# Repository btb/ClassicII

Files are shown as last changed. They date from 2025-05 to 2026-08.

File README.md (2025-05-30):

# ClassicII

Reproduction of Macintosh Classic II

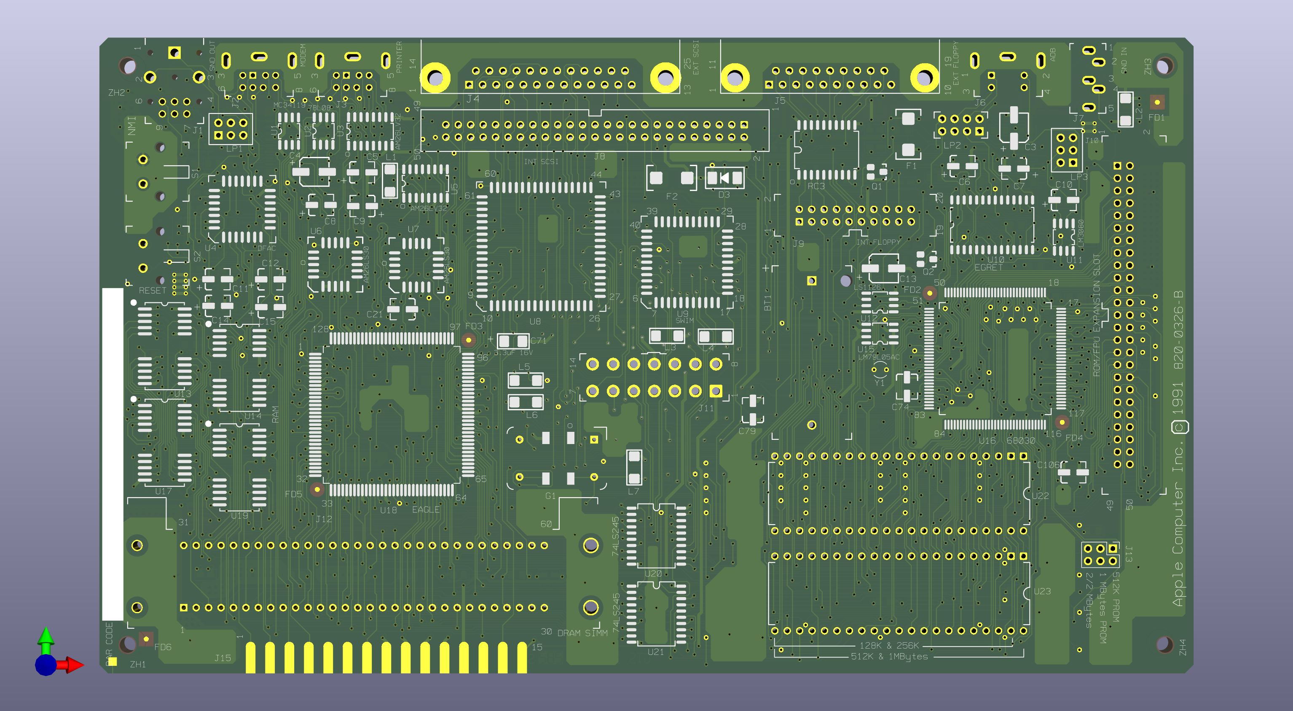
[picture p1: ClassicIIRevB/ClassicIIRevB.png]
Rendering of reproduced Class II logic board


This was reverse-engineered from a later-revision Classic II logic board. All components on the front side, and a handful of components on the back side, were removed, and the board was scanned.

Since my scanner isn't very accurate, scale-wise, the scans were resized and aligned to match the board's measurements.

The board was severely damaged by battery and capacitor leakage, but I was able to faithfully reproduce all connections.

The inner layers are used for various ground and power planes - you can make out a surprising amount of inner detail by backlighting the board and seeing what shines through the windows left by vias, etc., so these are also reproduced fairly accurately.

The [Bomarc schematics](documents/Bomarc%20schematics%20-%20corrected.pdf) for this board were useful as a reference, but they are for the earlier revision, and they do contain some inaccuracies.

## Issues

It's likely some of the signals of the undocumented Apple ASICs in [my schematic](ClassicIIRevB/ClassicIIRevB.pdf) aren't classified correctly.

The silkscreen markings of the PCB aren't as nice as I'd like yet.

There should be a "reloaded" version that will better serve those who need to replace their damaged boards. It should have footprints for both the older and the newer revision ROM chips. The footprints for the electrolytic caps should be widened to make them friendlier to replace with tantalums. The battery should accommodate a 2032 coin cell.

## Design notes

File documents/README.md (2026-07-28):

# Documents

## Classic_II_Schematic.pdf

Classic II schematics from Apple, posted to 68kmla forums after I did my reverse-engineering.

## Bomarc schematics - corrected.pdf

The Classic II schematics, as reverse-engineered by Bomarc Services, with corrections added by me.

## Developer Note.pdf

The Classic II Developer Note from Apple.

## Macintosh_Hardware_Overview_Feb91.pdf

Apple internal document describing the hardware of this era. The Classic II is referred to as "Apollo" here.

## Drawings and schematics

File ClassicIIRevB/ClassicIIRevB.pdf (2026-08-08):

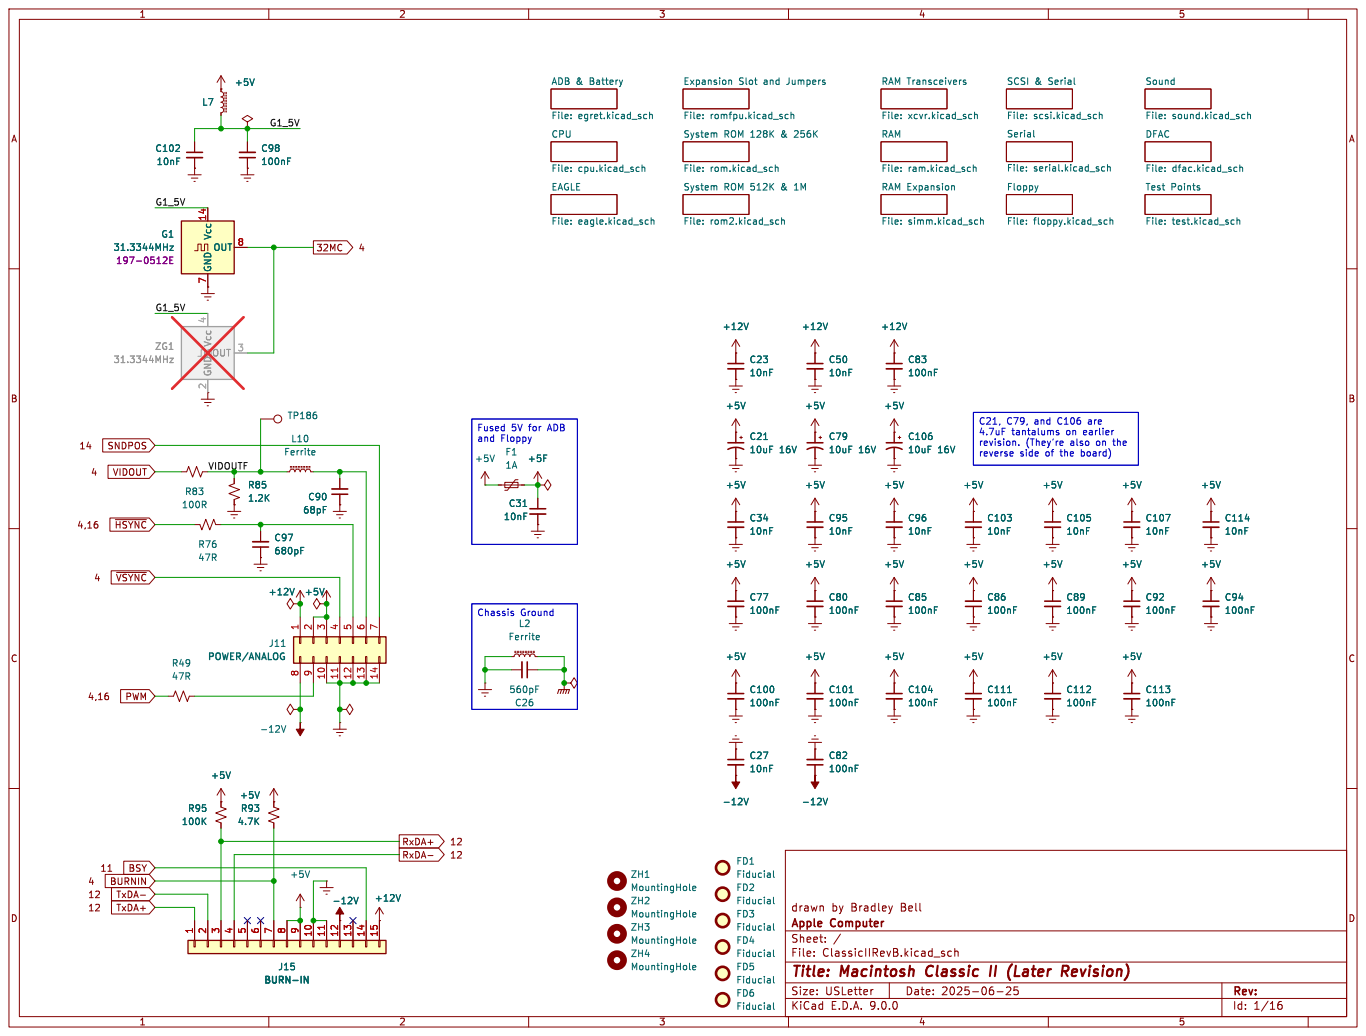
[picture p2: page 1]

Expansion Slot and Jumpers File: romfpu.kicad_sch EAGLE

File: dfac.kicad_sch Sound File: sound.kicad_sch Serial File: serial.kicad_sch RAM Transceivers File: xcvr.kicad_sch RAM

reverse side of the board) Fused 5V for ADB

L10 FerriteC90
and Floppy Chassis Ground C90

FD4 Fiducial FD2 Fiducial FD6 Fiducial FD1 Fiducial ZH3 MountingHole ZH2 MountingHole

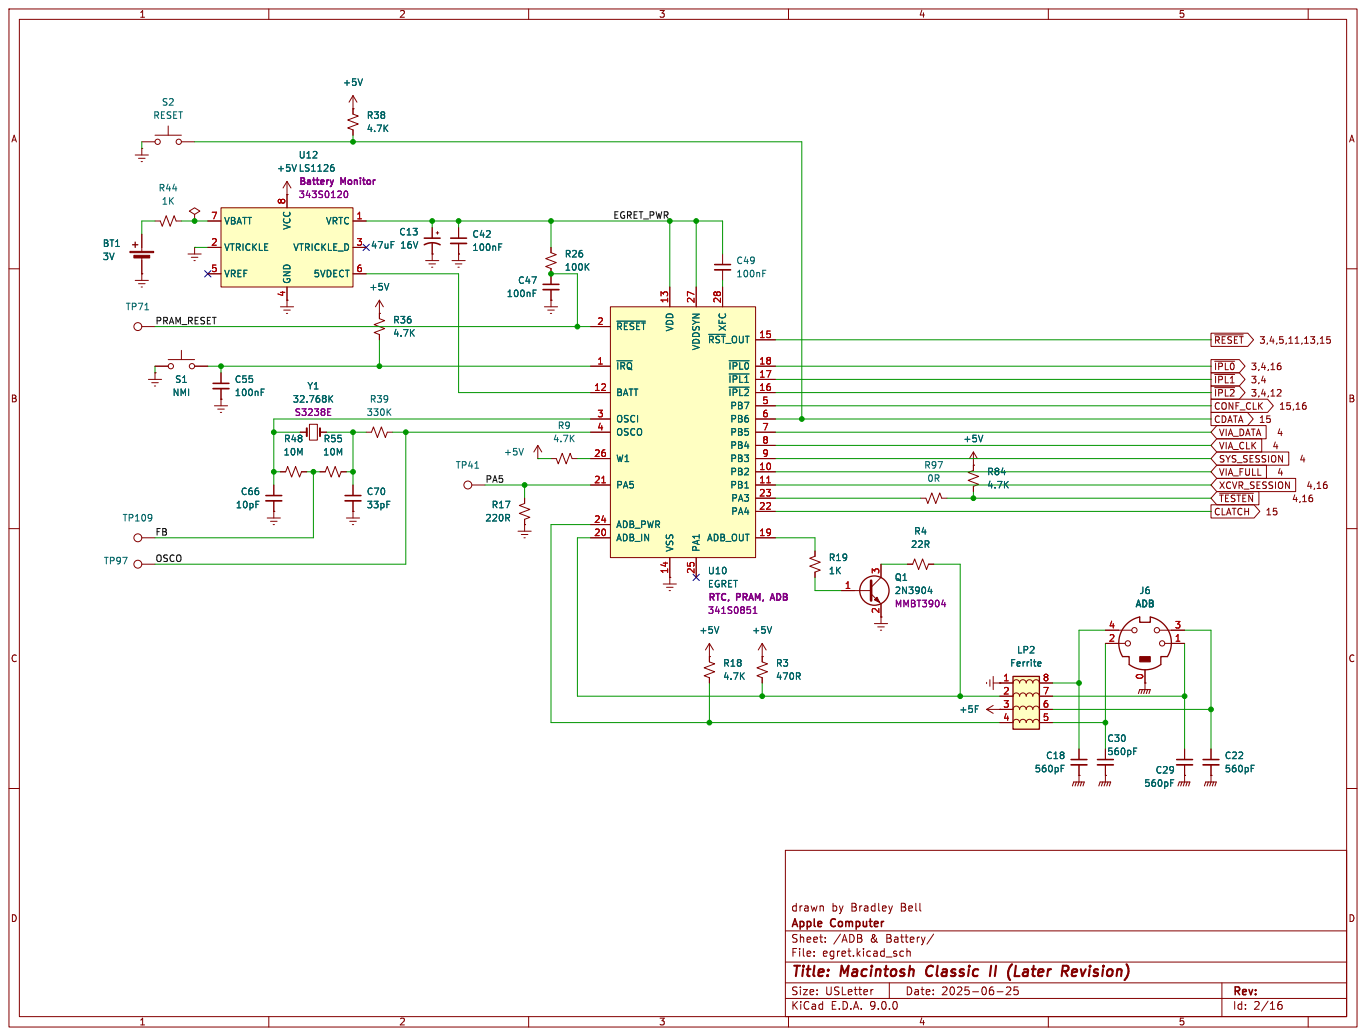
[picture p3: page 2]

4 VBATT 7 VTRICKLE 2 VREF 5 VRTC 1 VTRICKLE_D 3

U10 EGRET RTC, PRAM, ADB

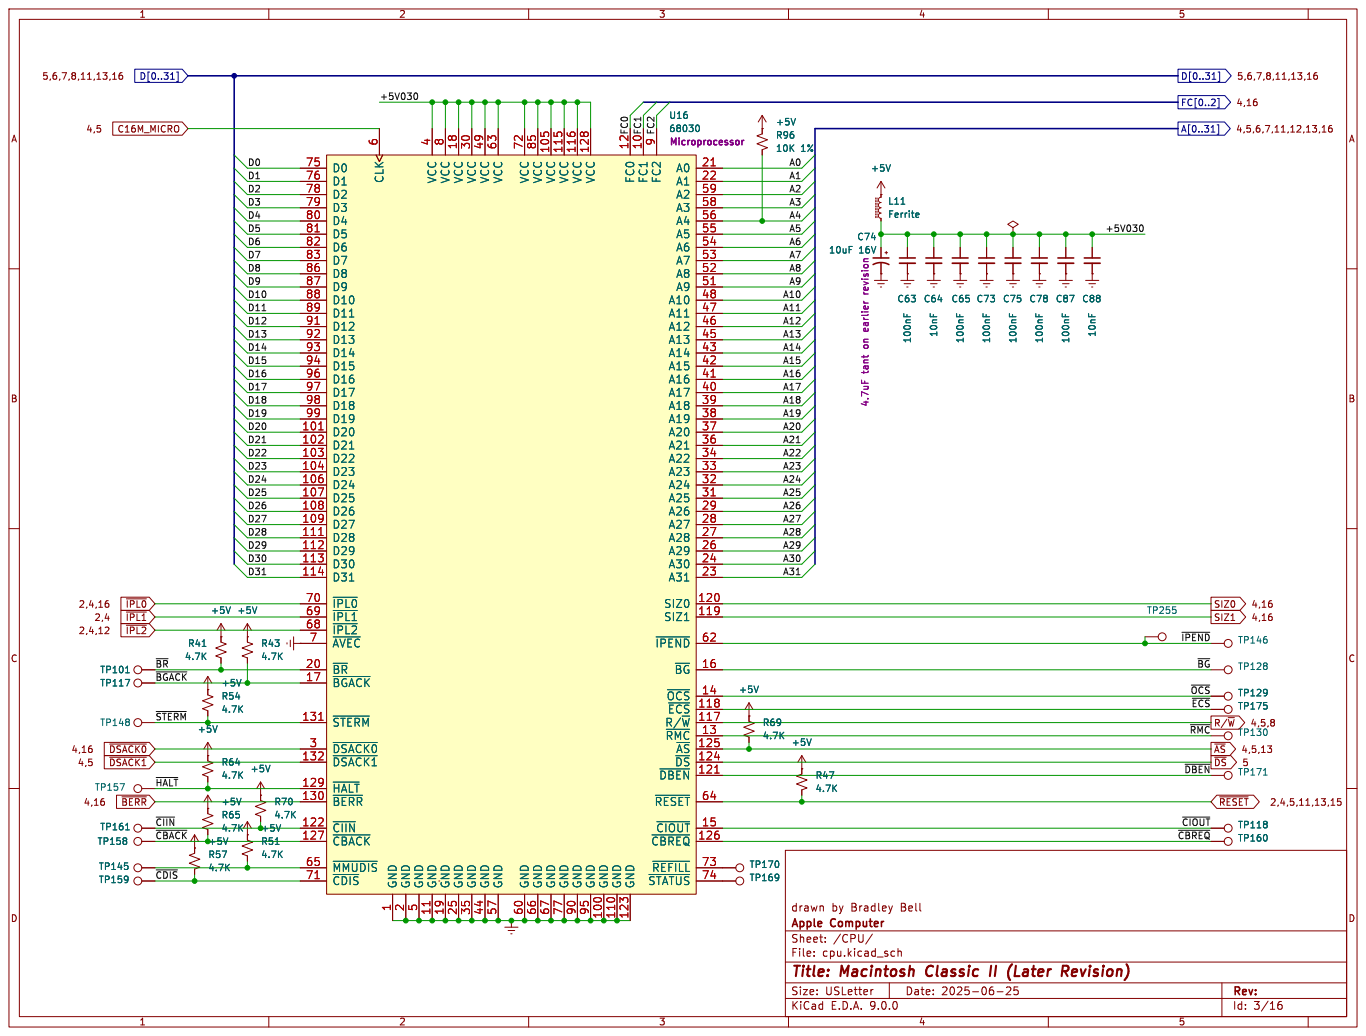
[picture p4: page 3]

8 GND 19 VCC 18 GND 25 VCC 30 GND 35 VCC 49 GND 44 VCC 63 GND 57 VCC 72 GND 60 VCC 85 GND 66 VCC 105 GND 67 VCC 115 GND 77 VCC 116 GND 90 VCC 128 GND 95 GND 100 GND 110 FC0 12 GND 123 FC1 10 FC2

9 A0 21 A1 22 A2 59 A3 58 A4 56 A5 55 A6 54 A7 53 A8 52 A9 51 A10 48 A11 47 A12 46 A13 45 A14 43 A15 42 A16 41 A17 40 A18 39 A19 38 A20 37 A21 36 A22 34 A23 33 A24 32 A25 31 A26 29 A27 28 A28 27 A29 26 A30 24 A31 23 SIZ0 120 SIZ1 119 ~{IPEND}62 ~{BG}16 ~{OCS}14 ~{ECS}118 R/~{W}117 ~{RMC}13 ~{AS}125 ~{DS}124 ~{DBEN}121 ~{RESET}64 ~{CIOUT}15 ~{CBREQ}126 ~{REFILL}73 ~{STATUS}74

10uF 16V4.7uF tant on earlier revision

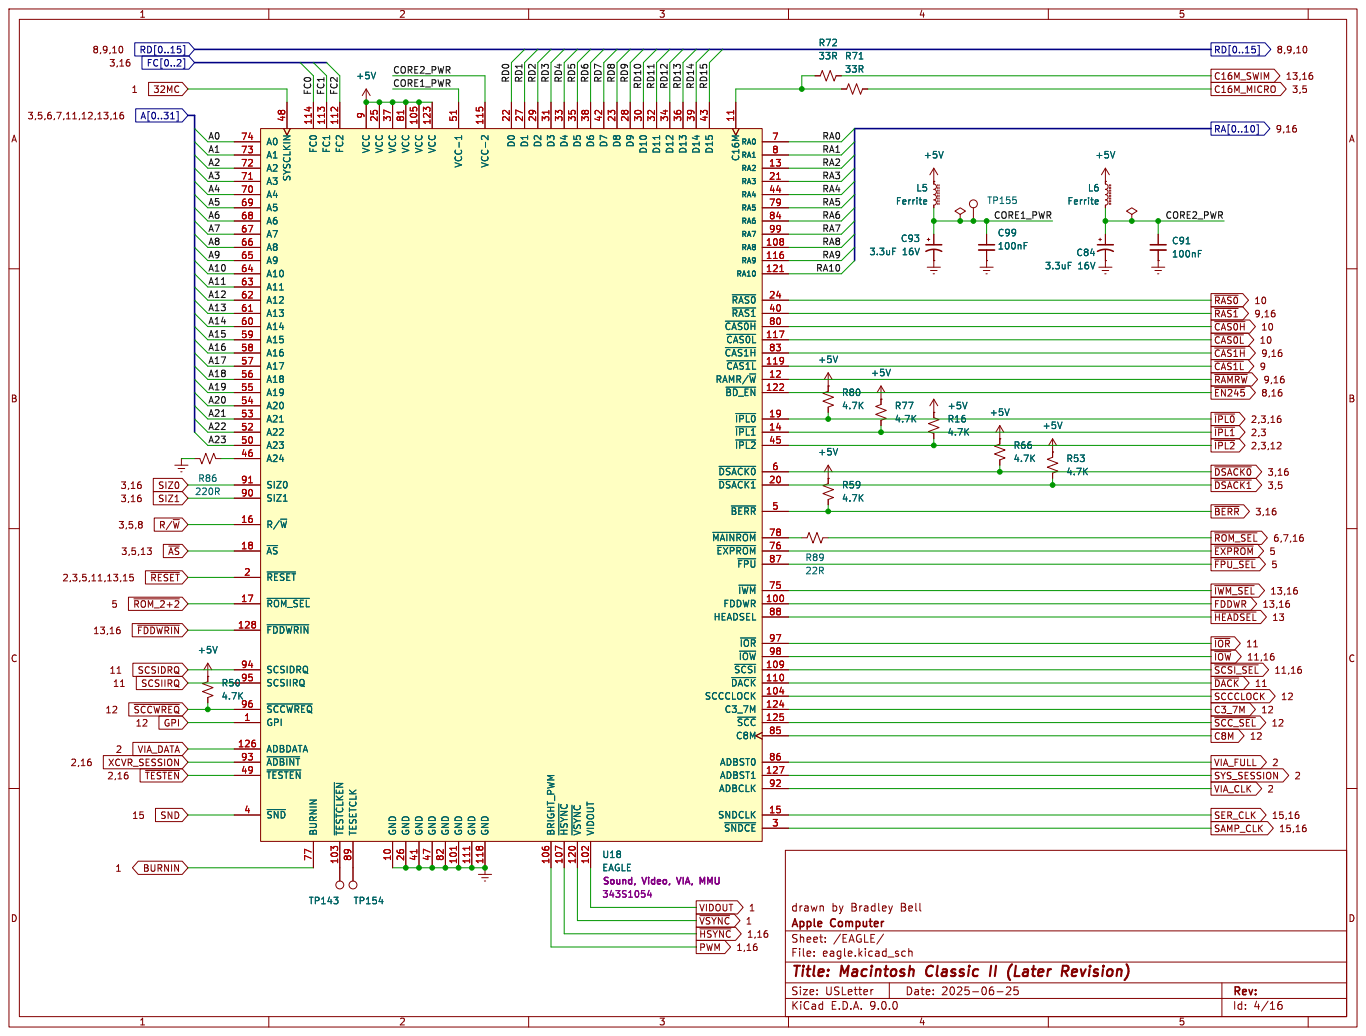
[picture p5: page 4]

9 VCC 25 VCC 37 GND 10 VCC 81 GND 26 VCC 105 GND 41 VCC 123 GND 47 GND 82 VCC-1 51 GND 101 GND 111 VCC-2 115 GND 118 D0 22 D1 27 D2 29 D3 31 BRIGHT_PWM 106 D4 33 ~{HSYNC} 107 D5 35 ~{VSYNC} 120 D6 38 VIDOUT 102 D7 42 D8 23 D9 28 D10 30 D11 32 D12 34 D13 36 D14 39 D15 43 C16M 11 RA0 7 RA1 8 RA2 13 RA3 21 RA4 44 RA5 79 RA6 84 RA7 99 RA8 108 RA9 116 RA10 121 ~{RAS0} 24 ~{RAS1} 40 ~{CAS0H} 80 ~{CAS0L}117 ~{CAS1H} 83 ~{CAS1L}119 RAMR/~{W} 12 ~{BD_EN}122 ~{IPL0} 19 ~{IPL1} 14 ~{IPL2} 45 ~{DSACK0} 6 ~{DSACK1} 20 ~{BERR} 5 ~{MAINROM}78 ~{EXPROM} 76 ~{FPU} 87 ~{IWM}75 FDDWR 100 HEADSEL 88 ~{IOR} 97 ~{IOW}98 ~{SCSI}109 ~{DACK}110 SCCCLOCK 104 C3_7M 124 ~{SCC}125 C8M 85 ADBST0 86 ADBST1 127 ADBCLK 92 SNDCLK 15 ~{SNDCE} 3 R50

9 VCC 25 VCC 37 GND 10 VCC 81 GND 26 VCC 105 GND 41 VCC 123 GND 47 GND 82 VCC-1 51 GND 101 GND 111 VCC-2 115 GND 118 D0 22 D1 27 D2 29 D3 31 BRIGHT_PWM 106 D4 33 ~{HSYNC} 107 D5 35 ~{VSYNC} 120 D6 38 VIDOUT 102 D7 42 D8 23 D9 28 D10 30 D11 32 D12 34 D13 36 D14 39 D15 43 C16M 11 RA0 7 RA1 8 RA2 13 RA3 21 RA4 44 RA5 79 RA6 84 RA7 99 RA8 108 RA9 116 RA10 121 ~{RAS0} 24 ~{RAS1} 40 ~{CAS0H} 80 ~{CAS0L}117 ~{CAS1H} 83 ~{CAS1L}119 RAMR/~{W} 12 ~{BD_EN}122 ~{IPL0} 19 ~{IPL1} 14 ~{IPL2} 45 ~{DSACK0} 6 ~{DSACK1} 20 ~{BERR} 5 ~{MAINROM}78 ~{EXPROM} 76 ~{FPU} 87 ~{IWM}75 FDDWR 100 HEADSEL 88 ~{IOR} 97 ~{IOW}98 ~{SCSI}109 ~{DACK}110 SCCCLOCK 104 C3_7M 124 ~{SCC}125 C8M 85 ADBST0 86 ADBST1 127 ADBCLK 92 SNDCLK 15 ~{SNDCE} 3 U18 EAGLE

Sound, Video, VIA, MMU

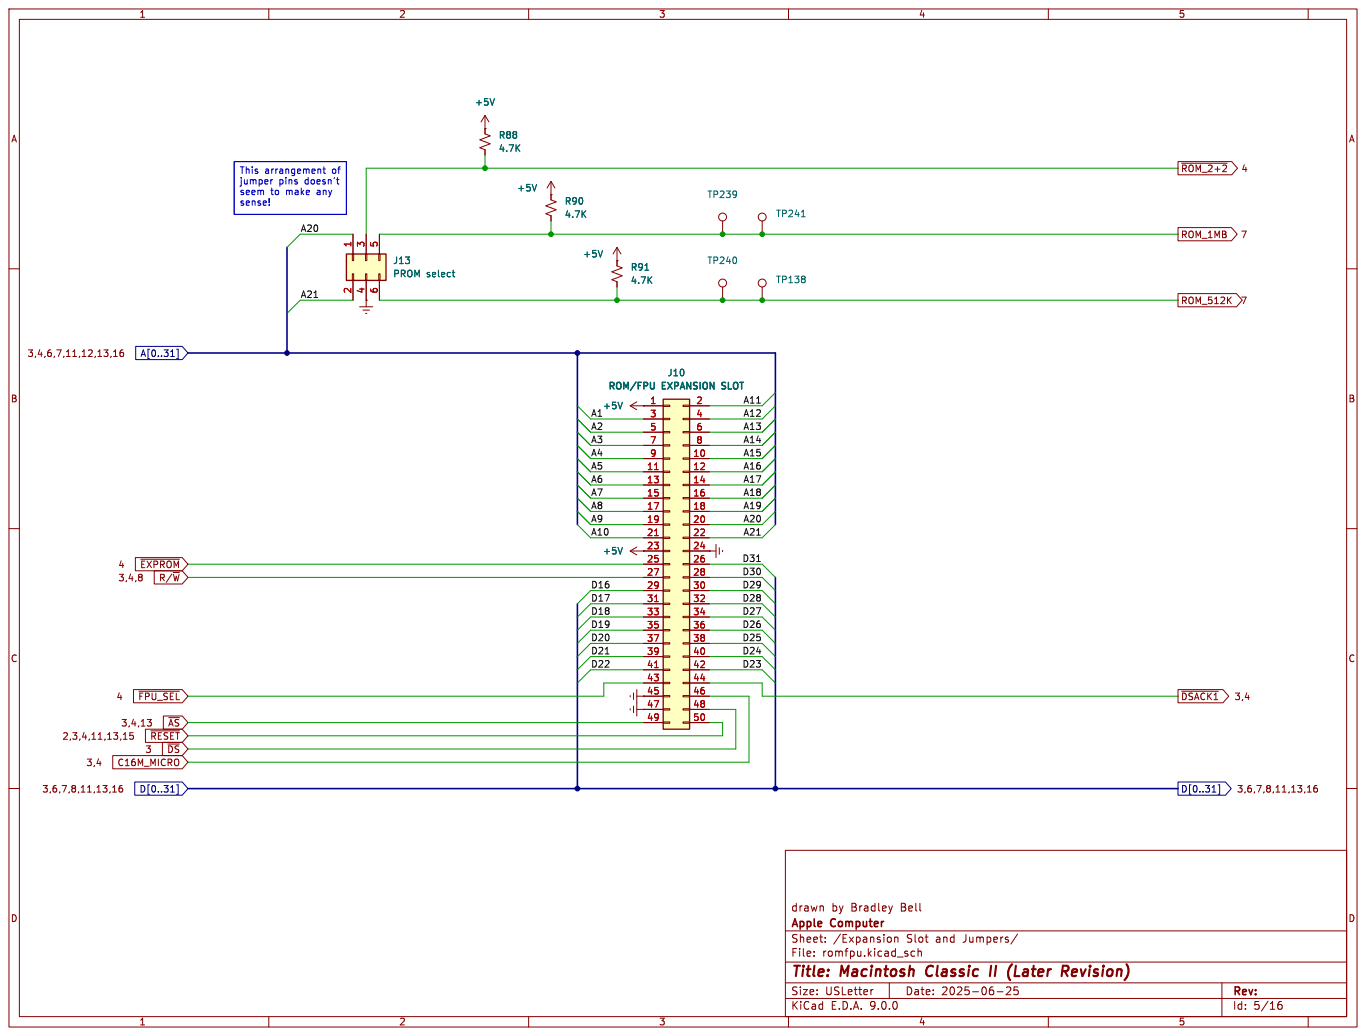
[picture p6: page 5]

jumper pins doesn't seem to make any

J10 ROM/FPU EXPANSION SLOT

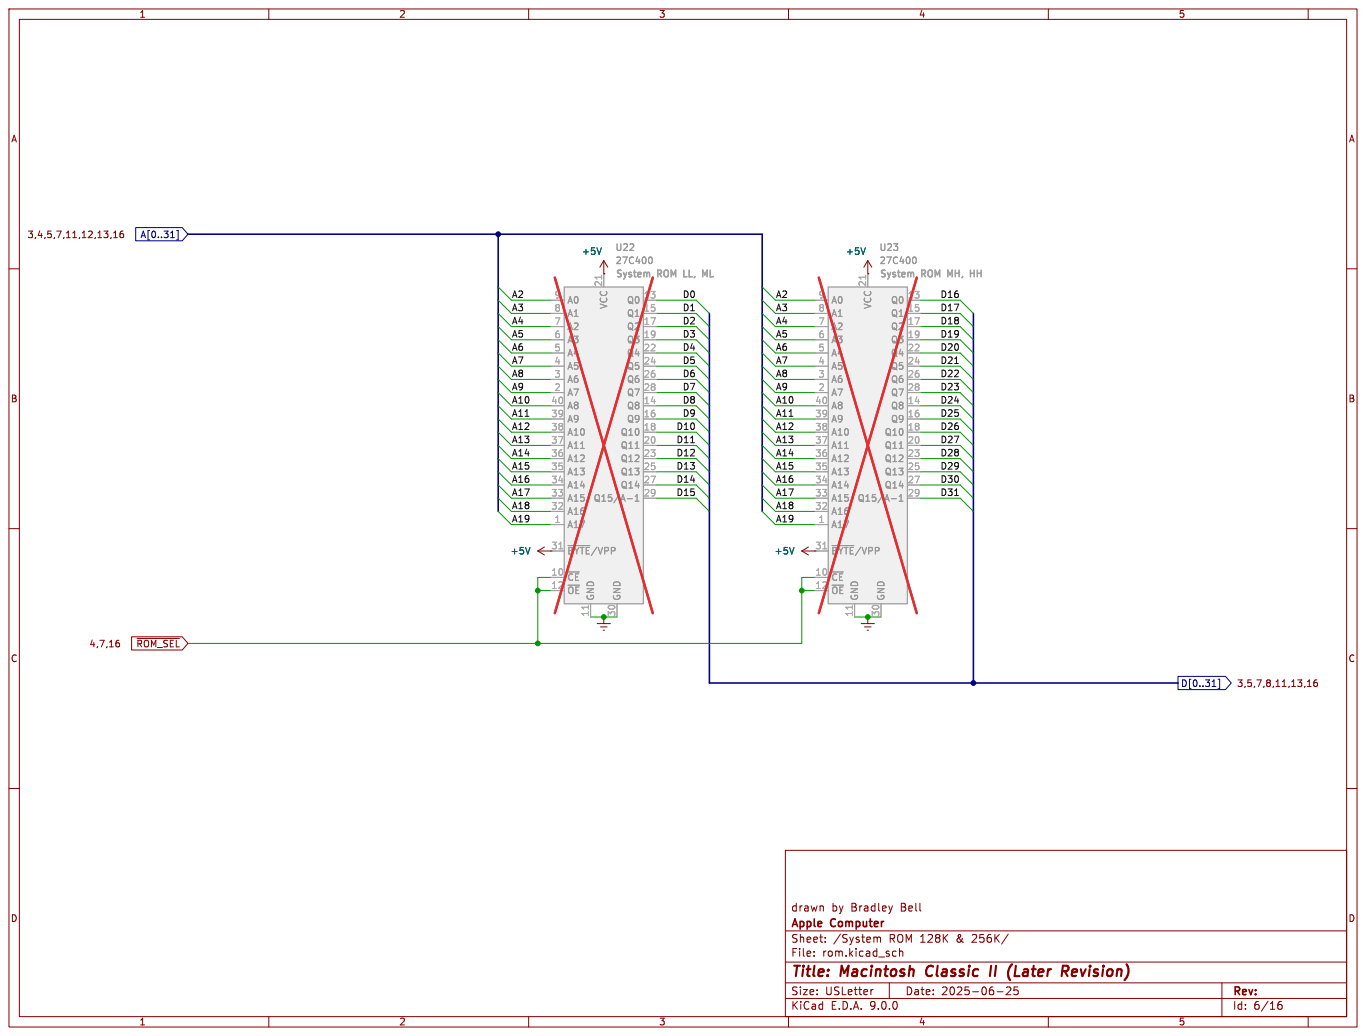
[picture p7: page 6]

27C400 System ROM MH, HH

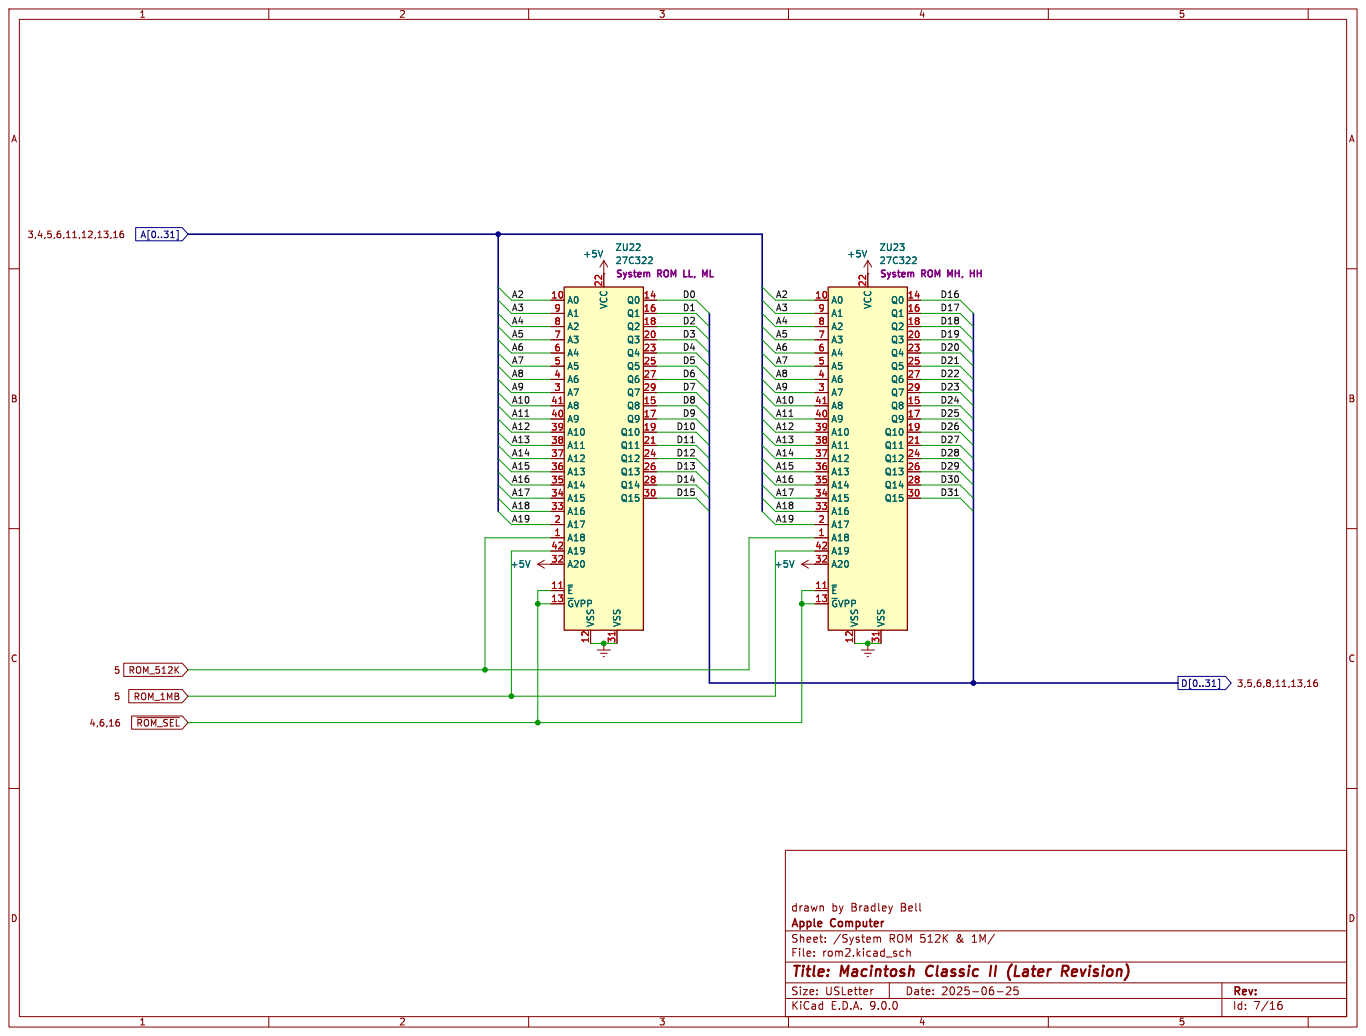
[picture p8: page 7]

27C322 System ROM MH, HH

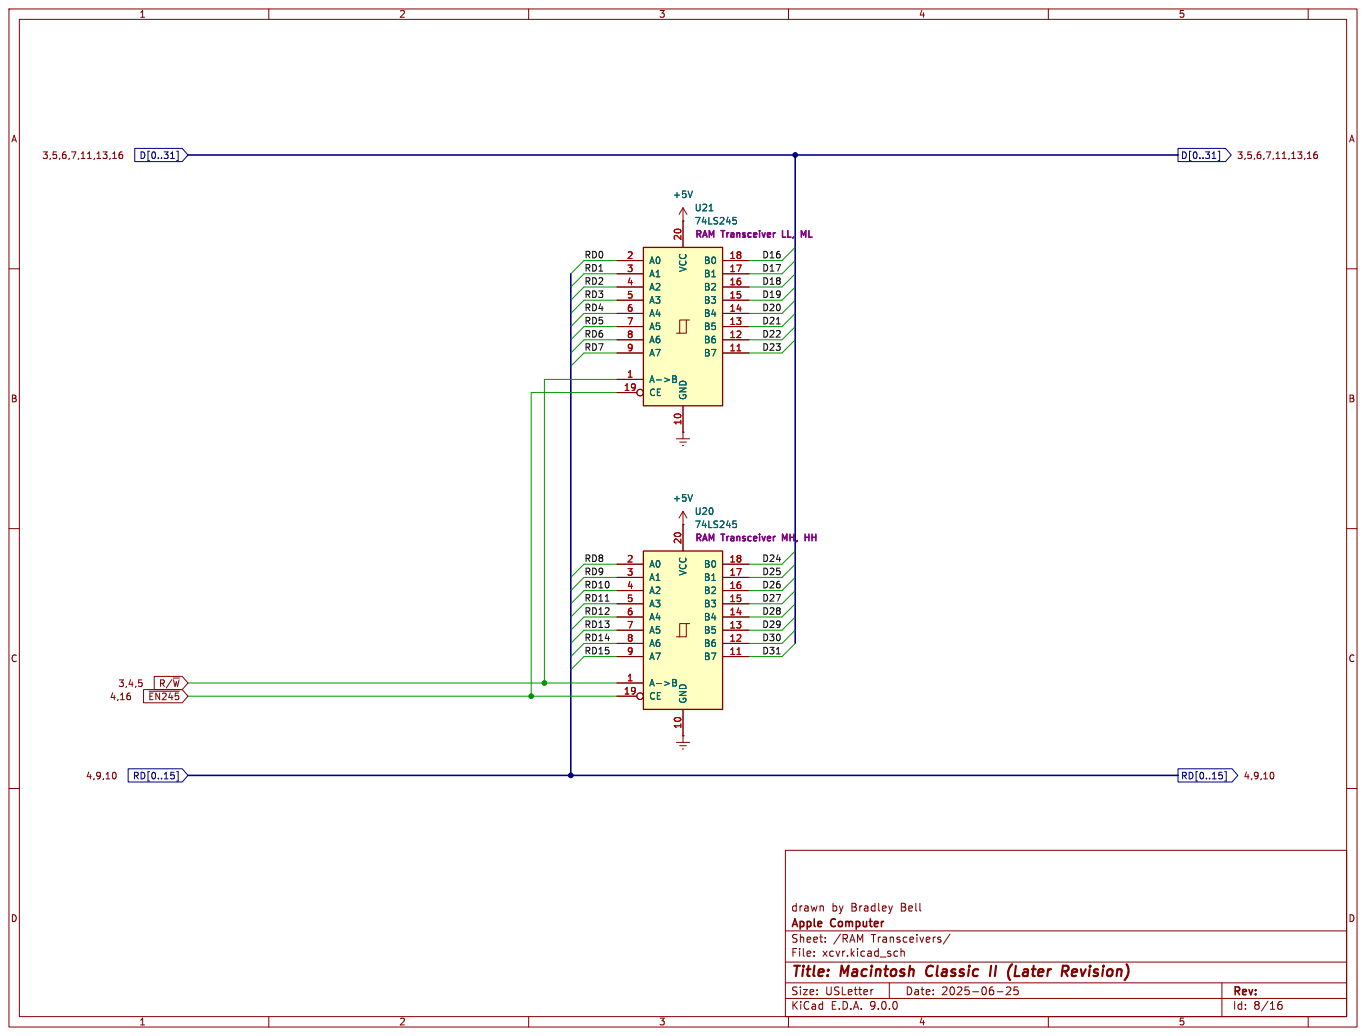
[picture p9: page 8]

74LS245 RAM Transceiver LL, ML

74LS245 RAM Transceiver MH, HH

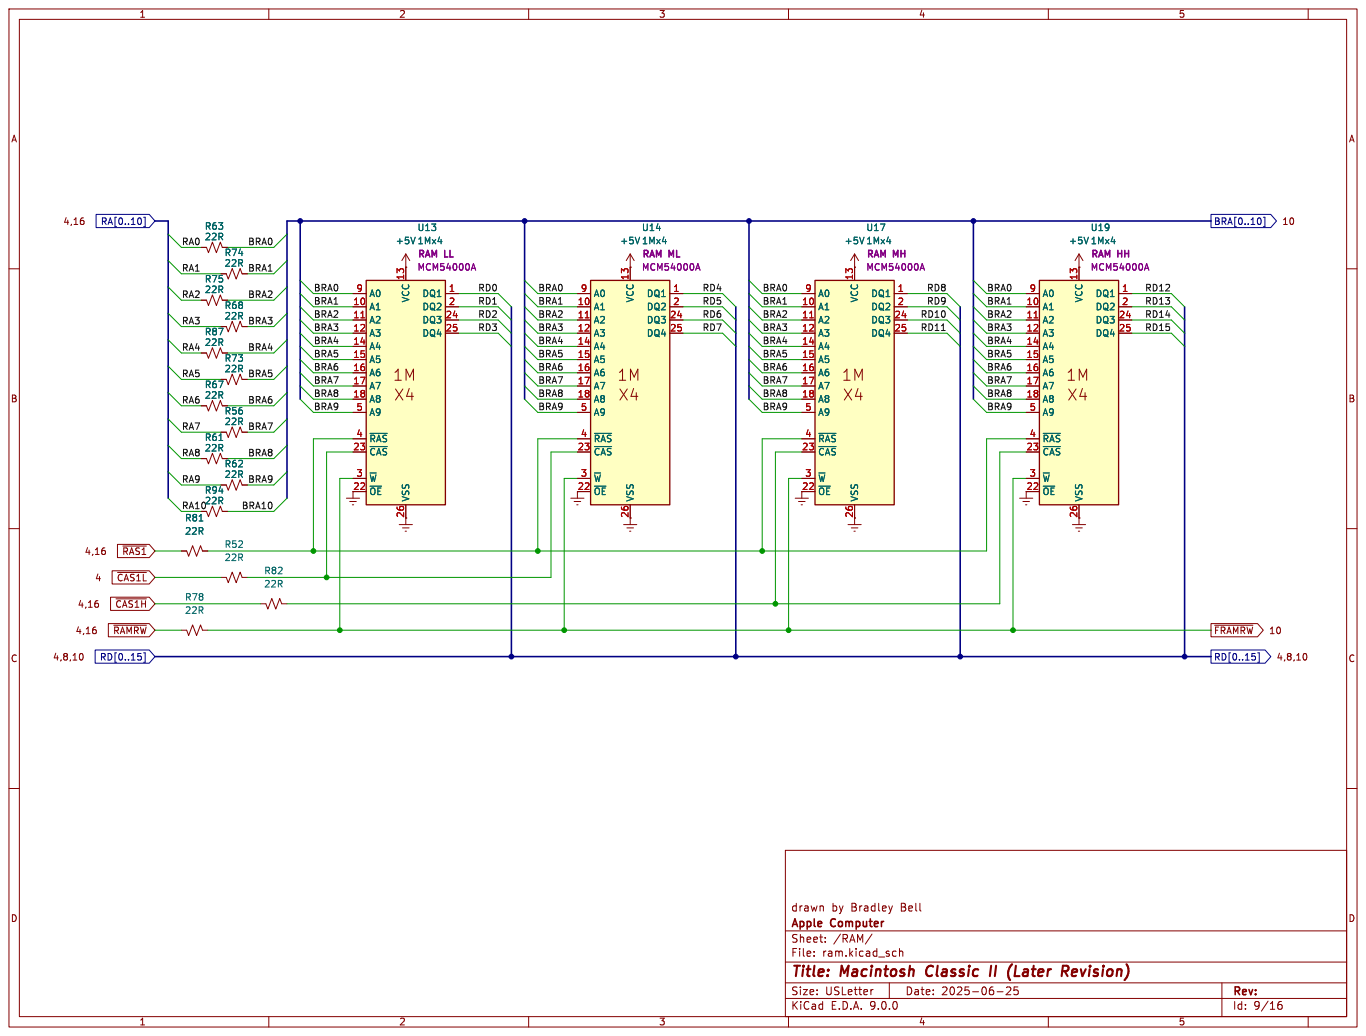
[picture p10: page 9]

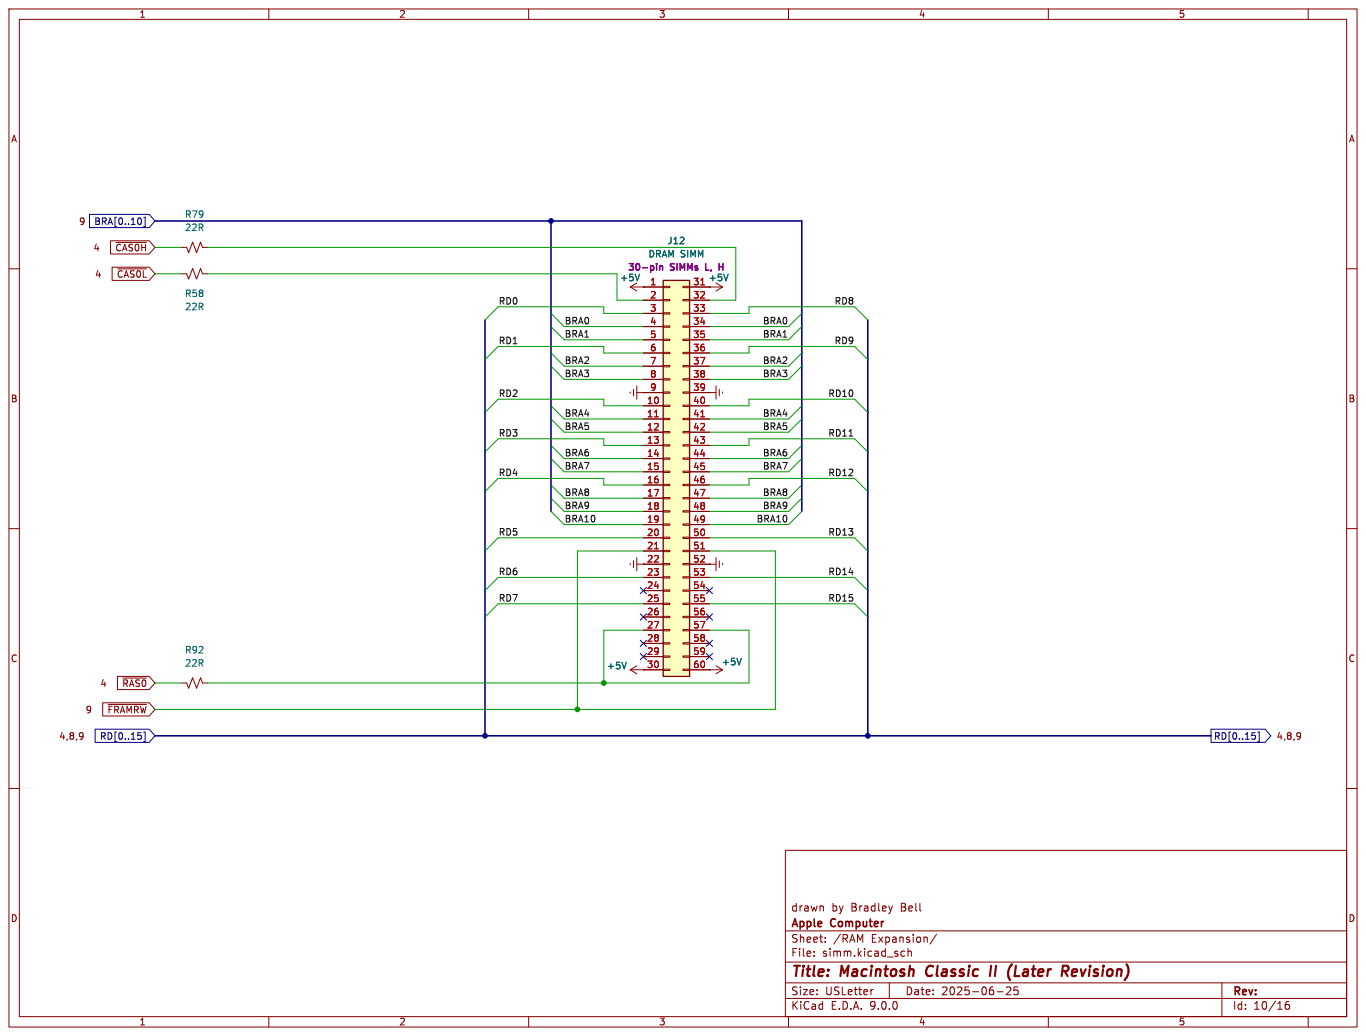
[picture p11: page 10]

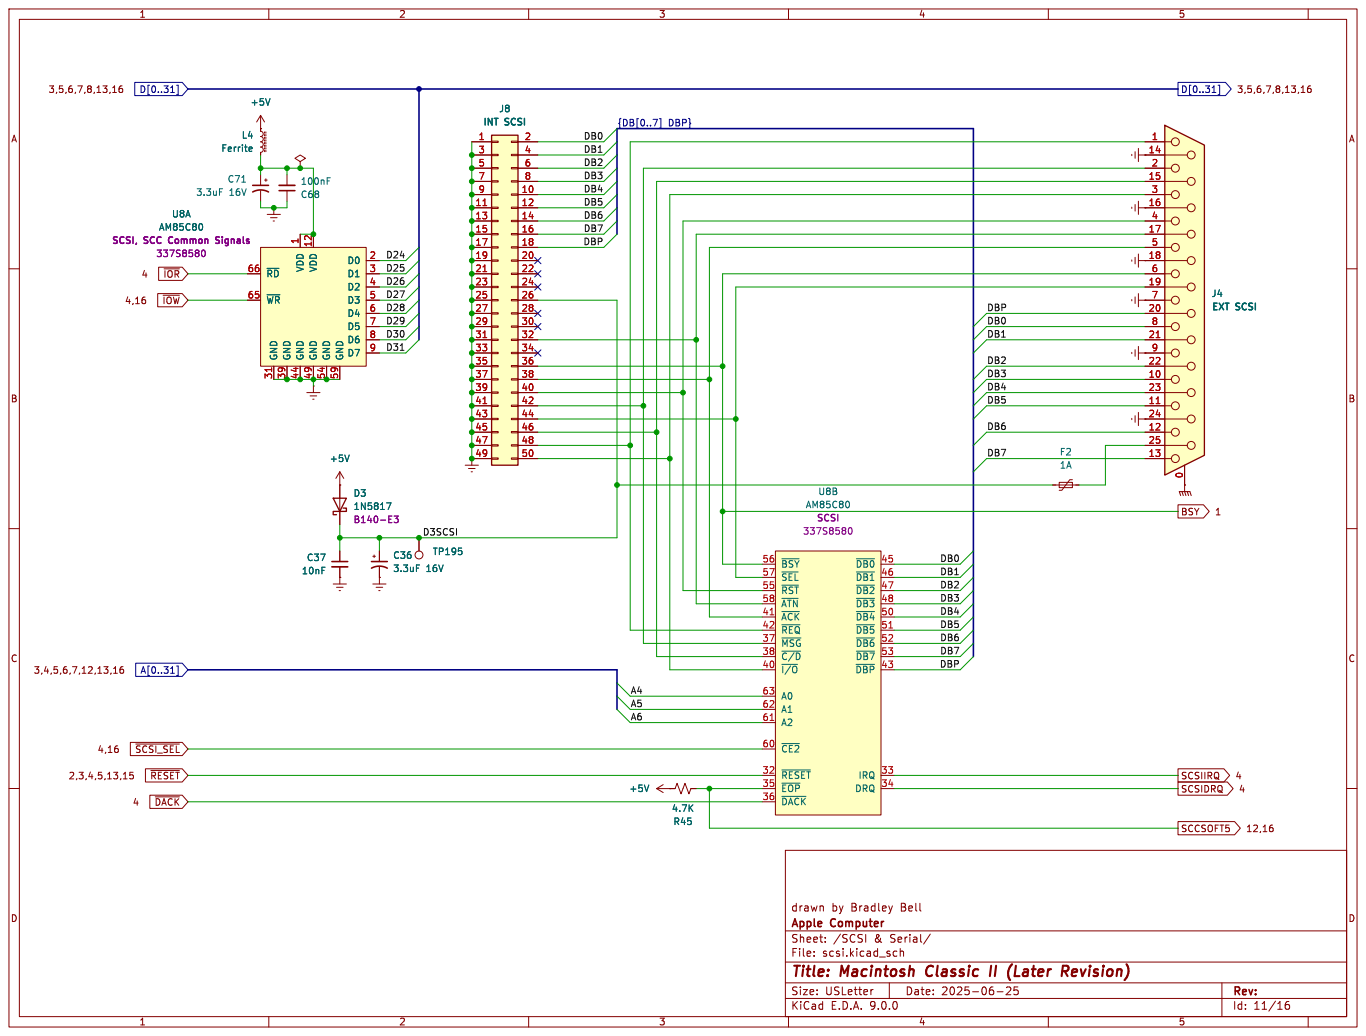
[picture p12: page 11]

1 GND 44 VDD 12 GND 49 GND 54 GND 59 D0 2 D1 3 D2 4 D3 5 D4 6 D5 7 D6 8 D7 9 U8A

AM85C80 SCSI, SCC Common Signals

1 GND 44 VDD 12 GND 49 GND 54 GND 59 D0 2 D1 3 D2 4 D3 5 D4 6 D5 7 D6 8 D7 9 C37

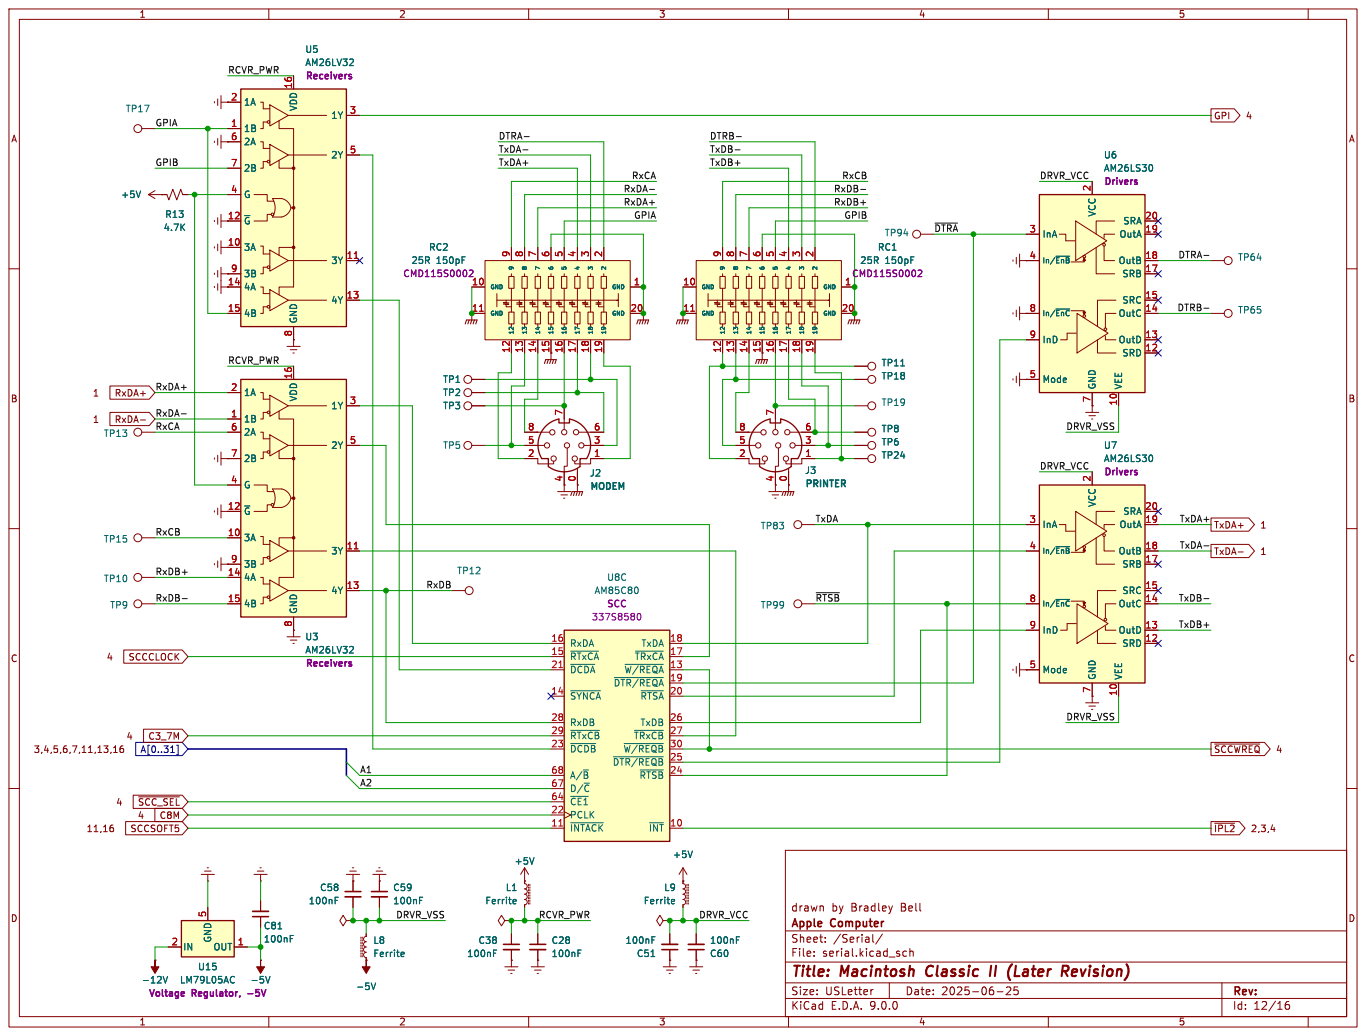
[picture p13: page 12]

2 SRA 20 OutA 19 OutB 18 SRB 17 SRC 15 OutC 14 OutD 13 SRD 12 U6AM26LS30 Drivers TP6 TP15 TP12 +5V

2 SRA 20 OutA 19 OutB 18 SRB 17 SRC 15 OutC 14 OutD 13 SRD 12 TP6 TP24 TP8 TP11 TP18

2 SRA 20 OutA 19 OutB 18 SRB 17 SRC 15 OutC 14 OutD 13 SRD 12 RC1

2 SRA 20 OutA 19 OutB 18 SRB 17 SRC 15 OutC 14 OutD 13 SRD 12 U7AM26LS30 Drivers


1 VCC 22 GND 12 VCC 30 GND 23 VCC 44 GND 34 D0 4 D1 5 D2 8 D3 9 D4 13 D5 14 D6 15 D7 18 ~{3.5SEL}16 HDSEL 38 ~{MOTORENB}10 DAT1BYTE 33 PHASE_0 35 PHASE_1 32 PHASE_2 36 PHASE_3 31 ~{ENBL1}20 ~{ENBL2}19 ~{WRREQ}3 WRDATA 2 U9SWIM

1 VCC 22 GND 12 VCC 30 GND 23 VCC 44 GND 34 D0 4 D1 5 D2 8 D3 9 D4 13 D5 14 D6 15 D7 18 ~{3.5SEL}16 HDSEL 38 ~{MOTORENB}10 DAT1BYTE 33 PHASE_0 35 PHASE_1 32 PHASE_2 36 PHASE_3 31 ~{ENBL1}20 ~{ENBL2}19 ~{WRREQ}3 WRDATA 2 C76

Id: 13/16 Title: Macintosh Classic II (Later Revision) File: floppy.kicad_sch Sheet: /Floppy/


earlier revision C32, C33, and C40 are


1 VLow 27 VHigh 28 Bypass 2 SerDOut 15 PWMOut 23


sheet and elsewhere are clearly
just left over pads from the earlier board revision.

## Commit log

2025-05-25 Add project files
    [ClassicII.kicad_sch, cpu.kicad_sch, dfac.kicad_sch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]
2025-05-25 Add schematic pdf
2025-05-25 Fix page numbers
    [ClassicII.kicad_sch]
2025-05-25 Add Bomarc schematics, with (some) corrections
2025-05-26 Cosmetic improvements
    [cpu.kicad_sch, egret.kicad_sch, rom.kicad_sch]
2025-05-26 More schematic cleanup
    [egret.kicad_sch]
2025-05-30 More cleanup and cosmetic fixes
    [ClassicII.kicad_sch, cpu.kicad_sch, dfac.kicad_sch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]
2025-05-30 Rename and move to subdir
    [ClassicII.kicad_sch, ClassicIIRevB.kicad_sch, cpu.kicad_sch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]
2025-05-31 Show smaller ROM footprints
    [ClassicIIRevB.kicad_sch, cpu.kicad_sch, dfac.kicad_sch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]
2025-06-10 improved footprints and silkscreens
    [ClassicIIRevB.kicad_sch, cpu.kicad_sch, dfac.kicad_sch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]
2025-06-13 Add Apple schematic
2025-06-14 Switch to some "official" net names
    [ClassicIIRevB.kicad_sch, cpu.kicad_sch, dfac.kicad_sch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]
2025-06-16 update exports
    [ClassicIIRevB.kicad_sch, cpu.kicad_sch, dfac.kicad_sch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]
2025-06-21 Corrections to SMDs, more improved footprints
    The later revision board reproduction design is now complete.
    [ClassicIIRevB.kicad_sch, cpu.kicad_sch, dfac.kicad_sch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]
2026-08-08 Fix zones
    [ClassicIIRevB.kicad_sch, cpu.kicad_sch, dfac.kicad_sch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]
2026-08-08 Ground jumper/bridge is really net tie
    [ClassicIIRevB.kicad_sch, cpu.kicad_sch, dfac.kicad_sch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]
